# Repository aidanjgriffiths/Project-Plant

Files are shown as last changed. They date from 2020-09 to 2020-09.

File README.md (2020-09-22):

# Plantiful
#### A Powerful Embedded Monitoring Device for plant Enthusiasts
This page aims to document the source code, software and hardware incorporated in the development and production of the Plantiful prototype.

## Software
### Android Studio  
Used for developing a mobile app that will collect sensor data and provide information to the user regarding the state of their plants. 
Many people possess Android phones. Group members have experience programming in Java on this platform. 
### PHP Storm  
Modern PHP IDE for developing Web Applications within several Web Environment's. This provides our Users with a Convenient platform for viewing Plant Data, with regard to the health status of their plants, the weekly requirements from the User in terms of providing the appropriate nourishments for the Plants, and the projected requirement's in the future.
### MySQL Workbench
Interface directly to the Database hosted in the cloud, allowing for effective and simple queries and modifications to the Database
### AWS Lightsail
Web Sever Hosting Service on Amazon Web Services, which hosts the Virtual Web Server, running a Headless Ubuntu Instance, with a LAMP (LAMP) stack pre-installed on the operating system  
### AWS MySQL RDS
Relational Database Service for the Cloud MySQL Database, for access from the Web Application and Android Application. This is the central point for the back-end configuration of the MySQL Database Instance
### Arduino IDE 
IDE provides a coding platform for writing high level C/C++ based code that can be flashed to an Arduino board. 
Accessible coding platform. Runs on Windows. Basic setup and looping format. Many well-established libraries available. USB flashing. Debugging is simple using the provided serial terminal.
### AutoDesk Fusion 360 
Used for developing 3D designs for the hardware enclosure (prototype and final design). 
Accessible. At least one group member has experience developing models with this software. Parts can be assembled and animated. Enable direct export of 3D printing file. Schematic drawings are available for large scale production. 
### AutoDesk Eagle
Used for developing CAD schematic and printed circuit board designs for the embedded system final design. Program works in conjunction with Fusion 360 to purpose fit to the hardware shell.
### Cura 
Enables slicing and positioning of component pieces on 3D printing platform. 
Group member is in possession of this software and has experience using it for printing prototypes. 

## Hardware
### Uno R3 
Compact micro-processing unit with I/O ports for interfacing with moisture, temperature/humidity and light sensors. Minimal processing required except to transmit sensor data serially over Bluetooth.
Accessible, cost effective, and comes with an IDE that includes simplified coding functions for reading data from sensors and communicating serially with the proposed mobile application. Used for initial development, with later revisions using the same microcontroller (ATMEL ATMega328) in a bare configuration. 
### Moisture sensor 
DFRobot moisture sensor measures soil moisture, utilising an inbuilt transistor and associated discrete parts amplify a weak current between the probes into a 0-5v signal dependent on moisture. Will be used to determines if plant requires watering or is over-hydrated. 
Cheap, accurate and interfaces well with Arduino. No external libraries are required. 
### Temperature / Humidity sensor (DHT12)
Digital temperature and humidity sensor to determine ambient environmental parameters that determine the suitability of the conditions for optimal plant development. Highly reliable and fast response. -40 - 80C temperature range with error of +/- 0.5C, 0-100% humidity range with an error of 2-5% over the range. Easy to interface with Arduino with easy to use, highly available external libraries.
### Ambient light sensor (5kOhm Light Dependent Resistor)
Measures ambient light and reflects analog voltage to Arduino controller. Will be used to determine if the plant is receiving the correct amount of sunlight. 
Simple to use and interfaces relatively easily with Arduino requiring a single pull-up resistor as the only extra part. No additional libraries required, but basic calibration required.
### HC-05 Bluetooth module 
Enables Bluetooth connection with mobile device to communicate sensor data serially. 
Easy to setup and maintain a reliable connection with a mobile phone. Security is not a priority given the non-critical nature of the sensor data collected.

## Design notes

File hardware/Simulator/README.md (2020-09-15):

# Using the simulator

## Hardware
HC-05 should be connected via a 3.3v level shifter so that RX *from the HC-05* goes to pin 10 on the Arduino and TX *from the HC-05* goes to pin 11 on the Arduino. Also note that while you can supply the HC-05 with 5v for it's supply, things tend to be a litte more stable if run from the 3.3v from the Arduino, this will be required for the level shifter at any rate.

## Software

Once a serial connection is created to the HC-05, a single character is all that is required to illicit a response, with the idea being that this communication protocol will directly mirror that of the finished design. 

### Commands

`v` - Version: Return the version of the firmware currently installed. Simulator will return `SIMx.yy`, "proper" version will return "x.yy".
`r` - Reading: Take a reading and return all the values in a single burst. In the case of the simulator, there are defaults for all of the readings, but these readings will randomly drift for each reading.

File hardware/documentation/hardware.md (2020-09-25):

# Hardware design notes
Please see the Fritzing diagrams (or included exported JPG's) for details on how the spaghetti or breadboard versions are connected, or how the Testers are created.

# Hardware design notes - Naked MCU version

- A standard oscillator is formed using the following parts:
    * 16MHz Crystal - Across pins 9 and 10
    * 2x 22pf ceramic capacitors - tie pins 9 and 10 to ground.

- A standard 5V+ rail is generated using the following parts:
    * 7805 5V Regulator
    * 33uF Electrolytic capacitor - directly across the input pins. 
        This is a MINIMUM value part - larger is ok.
    * 9V Battery Snap - Fed into the In and Ground pins of the 7805 

- A standard 3.3V rail is generated using the following parts:
    * LM3940 3.3V regulator - Takes input from 7805 output
    * 100nF ceramic capacitor - Across the outputs of the LM3940.
        This is a precise part - a capacitance higher or lower than this
        runs the risk of an unstable or incorrect 3.3v rail

- The ATMega328 chip must have the following:
    * A 10kOhm pullup resistor to pin 1 (the reset line)
    * A small momentary switch from pin 1 to ground 
        - This is to allow programming by holding the reset pin low until the
          code is about to be uploaded, then released. This allows the bootloader
          to operate correctly and flash the new code.
    * A 47uF capacitor on the supply pins to help smooth voltage

- The bluetooth module is connected via a 3.3v level converter
    - The HC-05 must have the following:
        - The Enable pin must be tied to ground to prevent it entering AT Mode at startup
        - The VCC and ground must be sourced via the 3.3v rails
        - The TX pin on the HC-05 must be connected via the level shifter to pin 17
        - The RX pin on the HC-05 must be connected via the level shifter to pin 16

- The LDR operates with a matched 5kOhm resistor in a voltage divider configuration
    - One side of the divider goes to ground, the other to 5V, and the signal in
      between the two devices is fed into pin 23
    - PLEASE NOTE: The unit needs to be calibrated for the range of the particular LDR/resistor
      combination. Please see the README.md under the LDR Tester folder.

- The feedback LED is connected to pin 19 and ground via a 1kOhm resistor.
    - Note that this is higher than normal for a bright LED - This keeps the current
      down and therefore the battery usage lower.

- The DHT22 temperature/humidity sensor requires the following:
    - Vcc connected to the 5V rail
    - A solid ground connection
    - The data pin connected to pin 13 of the microcontroller

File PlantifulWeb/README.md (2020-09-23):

# Plantiful Web Application
The Plantiful Web Application is a Web Interface to the Plantiful Monitoring System, which allows a User to View their Data, and Analyse Statistics based on their Monitoring Activities and Health Patterns

## Hardware Infrastructure
### MySQL Cloud Database
This is used to centralise all user data for access from the Web Application. User Data is propagated from the Android Application to the Cloud Database, through the Web API. This is a one way connection between the Web Application and Android Device. The data which is propagated to the Cloud Database is never deleted, and acts as a history of the Activities of the User and the Plantiful System.

### Web Server 
The Web Server is an _Amazon Lightsail Instance_, which hosts a LAMP Stack of Web Technology. The LAMP Stack consists of the following Technologies:

+ Apache HTTP Server
+ PHP Server-Side Processing Language
+ Linux Operating System
+ MySQL Default Database (Redundant due to manual MySQL Cloud Database)

The Web Server hosts the _Hypertext Documents and Resources for the Website_, which is retrieved by a Client when requested by a Browser.

The Web Server also hosts the _Web API_ for access via the Android Application, for simple propagation of data to the Data Source.

### Client
The Client in the Computational Device which supports access the Web Application, via a Web Browser. The Client makes HTTPS requests for the Web Application from the Web Server, which supplies the Web Pages and Resources.

The Client hosts several support modules, which reduces development time. The following support modules are in the latest commit of the Web Application:

+ QR Module for Generating and Displaying QR Codes based on a generated String ID
+ JQuery Module for simpler Document Object Model (DOM) traversal
+ Chart.JS for efficient and effective Graohs and Visualisations of Data

The AJAX (Asynchronous Javascript and XML) approach is used to create Asynchronous calls to the Web Server, to retrieve certain data from the Data Source. This provides a dynamic experience for the user, and allows for changes to be made to the Web Application, based on modifications of the Data Source by other devices (for example, the Android Aplication).

### Android Device
The Android Device hosts the Android Application, which provides the functions for Monitoring Plants and Creating Plant Profiles for the User's Garden. This Data is propagated to the Database via a Web Communications Module in the Android Application. This Communciations Module interfaces with the database via Web API Calls to the database. This layer of abstraction between the Android Device and the Database allows for middle-man processing, and erroneous / currupt data prevention.

## Software Infrastructure
The following Software Stack was used to process and display the data and User Interface. 

### Web Front-End and Back-End Technologies

+ HTML5 for structuring and designing the framework and content of the Web Application
+ CSS3 for formatting and styling the Web Application 
+ PHP for Server-Side processing and access to the Data Source
+ JavaScript for client-side processing and asynchronous requests for resources from the Web Server

## Security
### SSL/ TLS Let's Encrypt
The Web Application is certified via _Let's Encrypt_ for Secure Connections. This means the Android Device and Client (Web Browser) Users can connect to the Web Server via HTTPS (Hypertext Transfer Protocol Secure), which ensures that the bidirectional communications between the Web Server and Client are encrypted, therefore preventing a large degree of Man-in-the-Middle attacks.

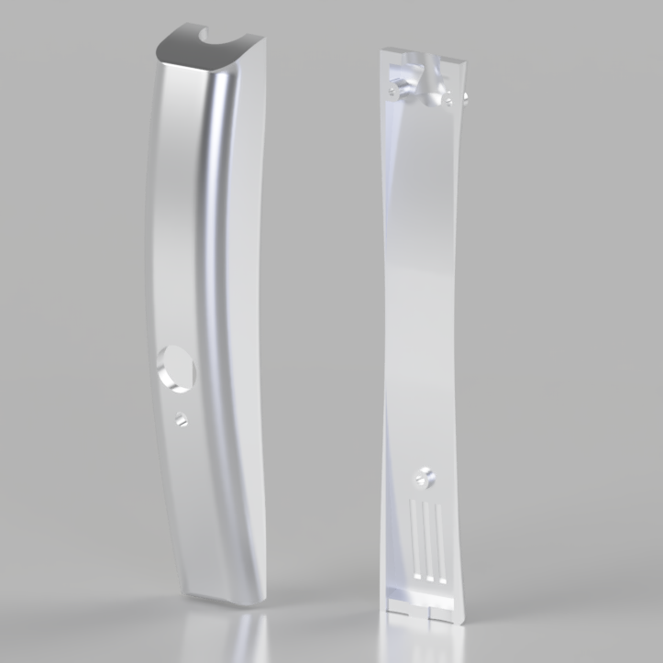
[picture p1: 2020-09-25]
hardware/3D_Models/Renders/render.PNG

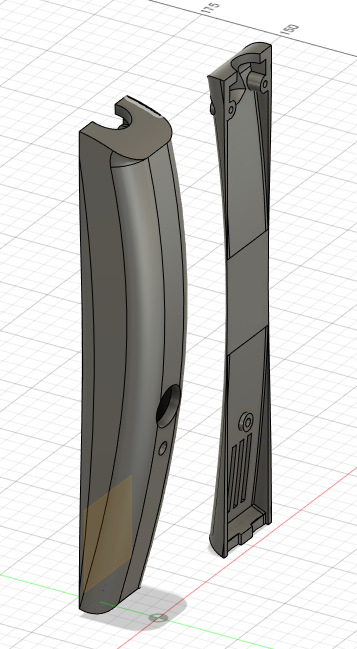
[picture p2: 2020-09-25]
hardware/3D_Models/Renders/front_v4.PNG

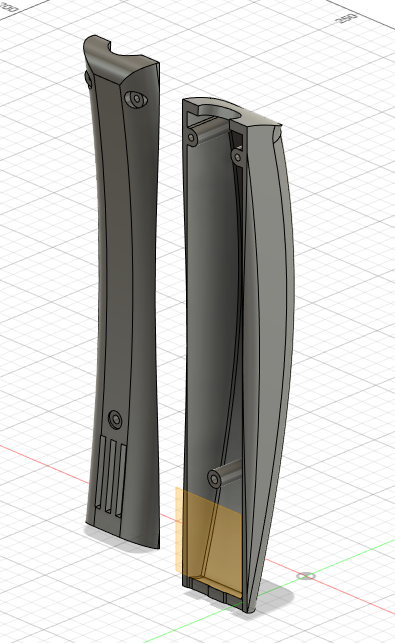
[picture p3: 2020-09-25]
hardware/3D_Models/Renders/left_v4.PNG

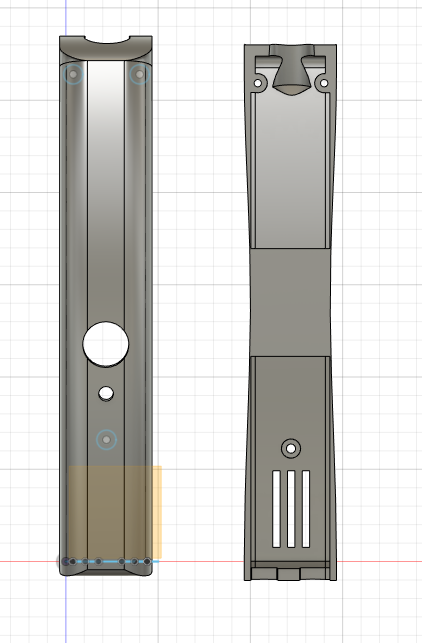
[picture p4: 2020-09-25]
hardware/3D_Models/Renders/3d_v4.PNG

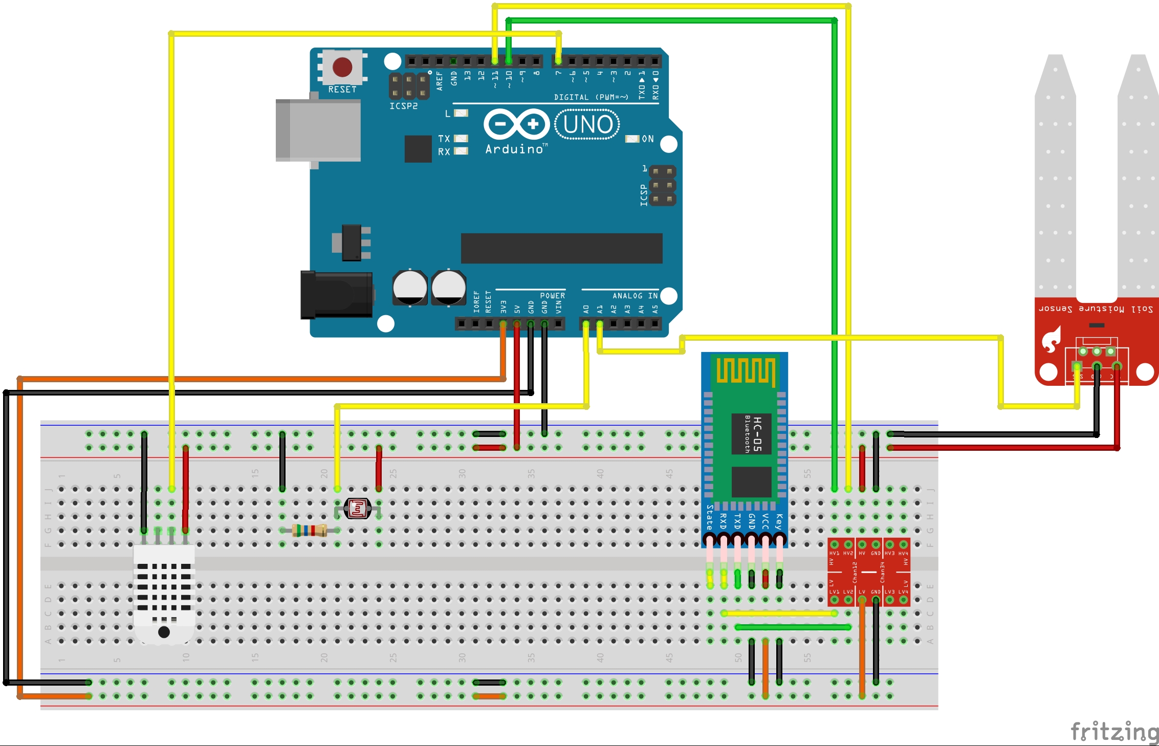
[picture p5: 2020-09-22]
hardware/documentation/Design 02 - Breadboarded.jpg

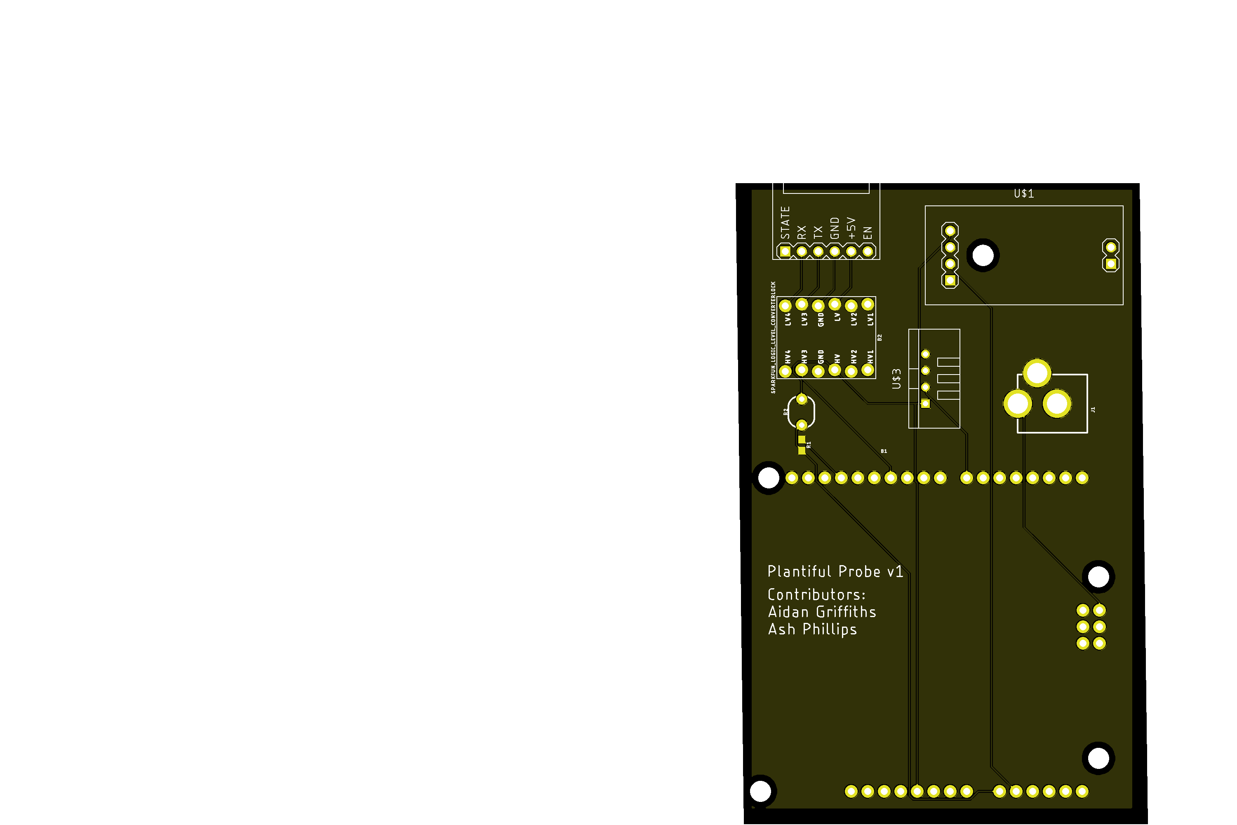
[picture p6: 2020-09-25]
hardware/PCB/Probe_PCB.png

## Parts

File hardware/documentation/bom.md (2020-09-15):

# Bill of Materials

## Introduction

This document will outline the total list of parts required for each variation/version of the hardware, including testers and intermediate revisions. This document will only detail the materials required. Connection and operation will be left to the design document.

## Suppliers

Most of the components in the below lists can be found from:
- Jaycar
- Core Electronics

## Testers
### Bluetooth Tester

* Arduino Uno/Nano
* HC-05 Bluetooth Module
* 5v-3.3v level converter module
* M-F Dupont wires

### DHT22 Tester

* Arduino Uno/Nano
* DHT22 Humidity/Temperature Sensor
* M-F Dupont wires

### LDR Tester

* Arduino Uno/Nano
* 5Kohm Light Dependent Resistor (CdS cell)
* 5.6Kohm 5% 1/4W resistor
* M-F Dupont wires
* Light duty hookup wire

### Moisture Tester

* Arduino Uno/Nano
* DFRobot resistive moisture sensor 

## "Spaghetti" version

Note: this is the first cut of the hardware design prior to using a breadboard to begin simplifying the setup.

* Arduino Uno/Nano
* HC-05 Bluetooth Module
* 5v-3.3v level converter module
* DHT22 Humidity/Temperature Sensor
* 5Kohm Light Dependent Resistor (CdS cell)
* 5.6Kohm 5% 1/4W resistor
* DFRobot resistive moisture sensor
* M-F Dupont wires
* Light duty hookup wire

## "Breadboard" version

Note: This is the first cut of the hardware design, using a breadboard to simplify the "spaghetti" wiring first used"

* Arduino Uno/Nano
* HC-05 Bluetooth Module
* 5v-3.3v level converter module
* DHT22 Humidity/Temperature Sensor
* 5Kohm Light Dependent Resistor (CdS cell)
* 5.6Kohm 5% 1/4W resistor
* DFRobot resistive moisture sensor
* M-F Dupont wires
* Light duty hookup wire
* Small breadboard (2x power rails, 2 sides of 5x30 tie points)

## "Naked MCU" version

Note: This is the first cut of the hardware design, using a raw ATMega328 microcontroller on a breadboard. This is the most physically robust design.

* Atmel ATMega328-PU DIP Microcontroller with Arduino bootloader
* USB-to-serial adapter (or Arduino Uno with ZIF Socket for programming)
* 16MHz Crystal
* 2x 22pf ceramic capacitors
* 7805 5V Regulator
* LM3940 3.3V regulator
* 9v battery snap
* 5mm green LED
* 3.3uF 5+V electrolytic capacitor
* 2x 47uF 5+V electrolytic capacitor
* 100nF ceramic capacitor
* Solid-core breadboard wiring (will be cut into individual lengths)
* 1kohm 5% 1/4w resistor
* 10kohm 5% 1/4w resistor
* Breadboard compatible momentary switch (can use a simple jumper wire if careful for reset of MCU when programming)
* HC-05 Bluetooth Module
* DHT22 Humidity/Temperature Sensor
* 5Kohm Light Dependent Resistor (CdS cell)
* 5.6Kohm 5% 1/4W resistor
* DFRobot resistive moisture sensor
* M-F Dupont wires
* Light duty hookup wire
* Small breadboard (2x power rails, 2 sides of 5x30 tie points)

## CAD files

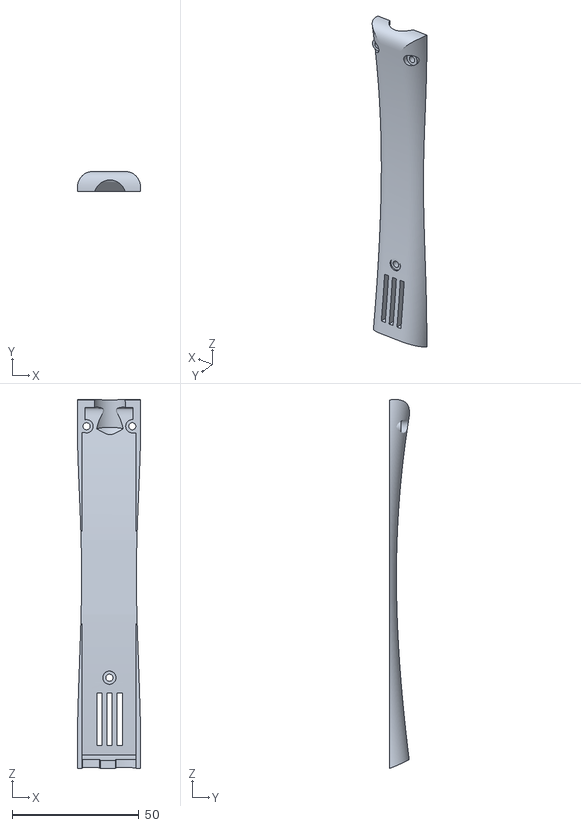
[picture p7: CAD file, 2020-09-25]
hardware/3D_Models/Models/probe_back_v5.stl
25.0 x 7.88 x 145.3

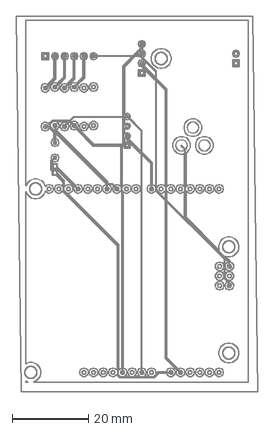
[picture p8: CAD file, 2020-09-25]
hardware/PCB/Probe_PCB.dxf
63.5 x 98.7 mm

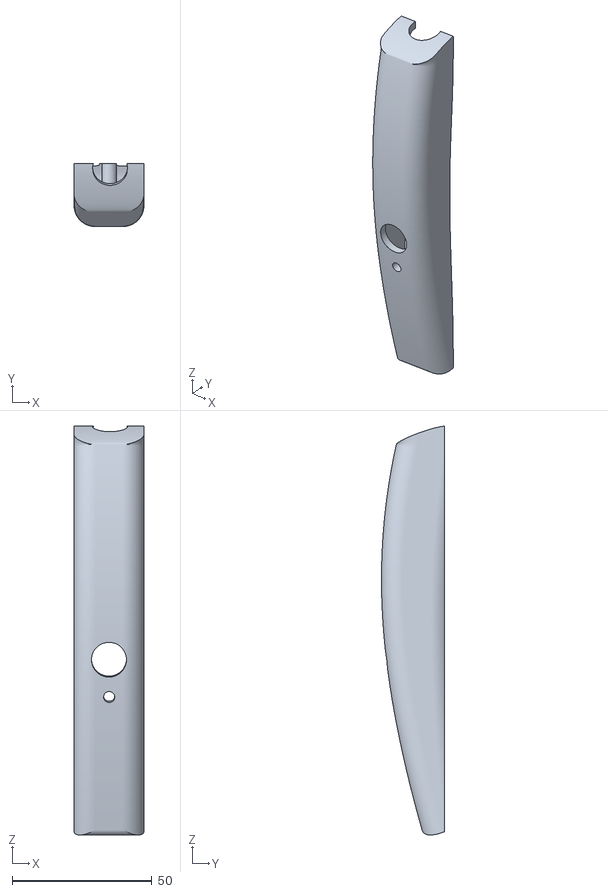
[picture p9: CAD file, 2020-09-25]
hardware/3D_Models/Models/probe_front_v5.stl
25.0 x 22.5 x 146.3

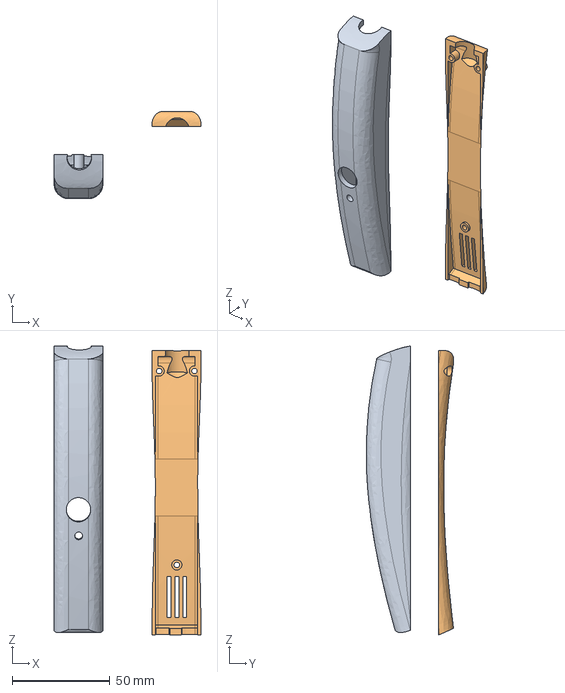
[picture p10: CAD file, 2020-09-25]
hardware/3D_Models/Models/probe_v5.step
75.0 x 44.7 x 147.5 mm

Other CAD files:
hardware/3D_Models/Models/probe_v5.obj

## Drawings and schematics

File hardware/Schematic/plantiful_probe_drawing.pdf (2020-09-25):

145.05 25 25

22.55

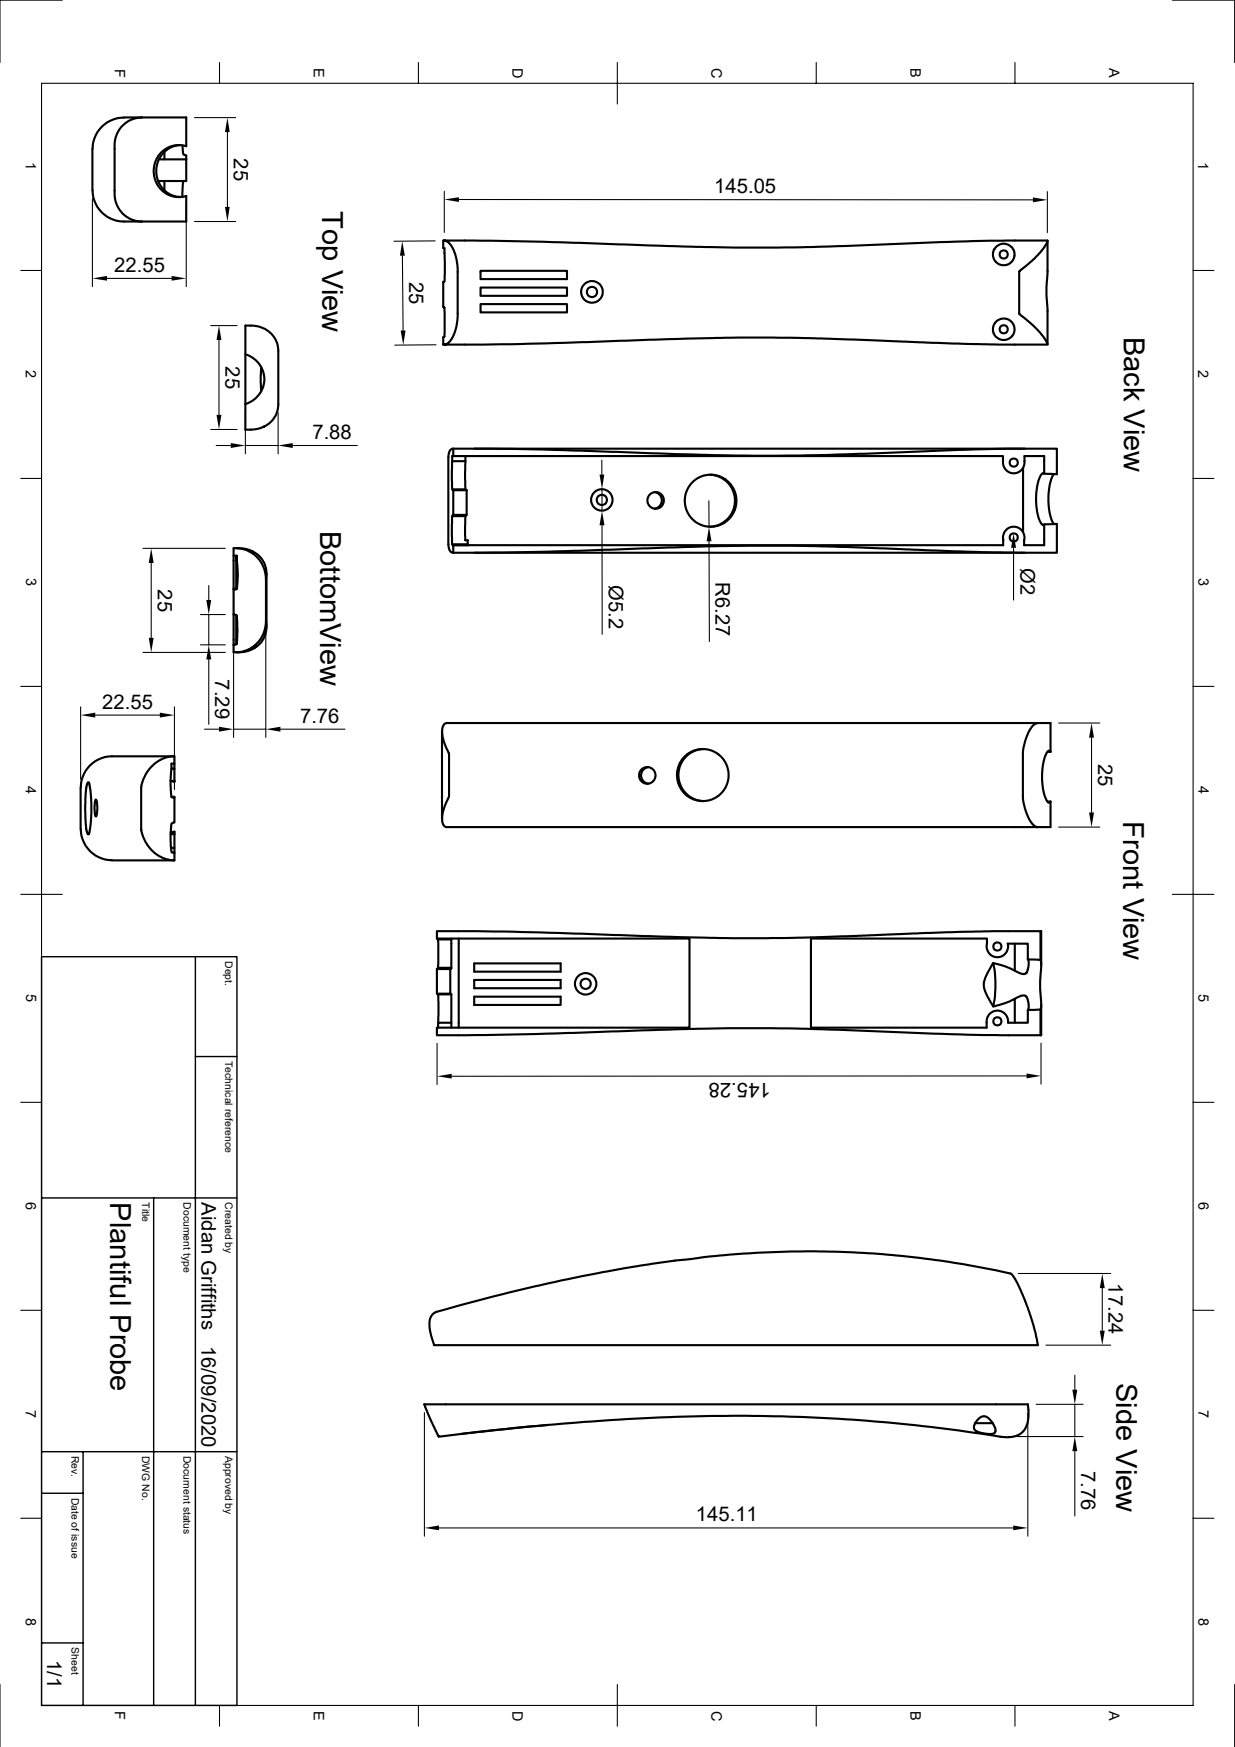
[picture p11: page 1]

1 A 2 3 4 5 6 7 8 1 2 3 4 5 6 7 8 FEDCB FEDCBA Dept. Technical reference Created by Approved by Title DWG No. Document type Document status Rev. Date of issue Sheet 16/09/2020 1/1 Plantiful Probe Aidan Griffiths Back View Front View Side View Top View

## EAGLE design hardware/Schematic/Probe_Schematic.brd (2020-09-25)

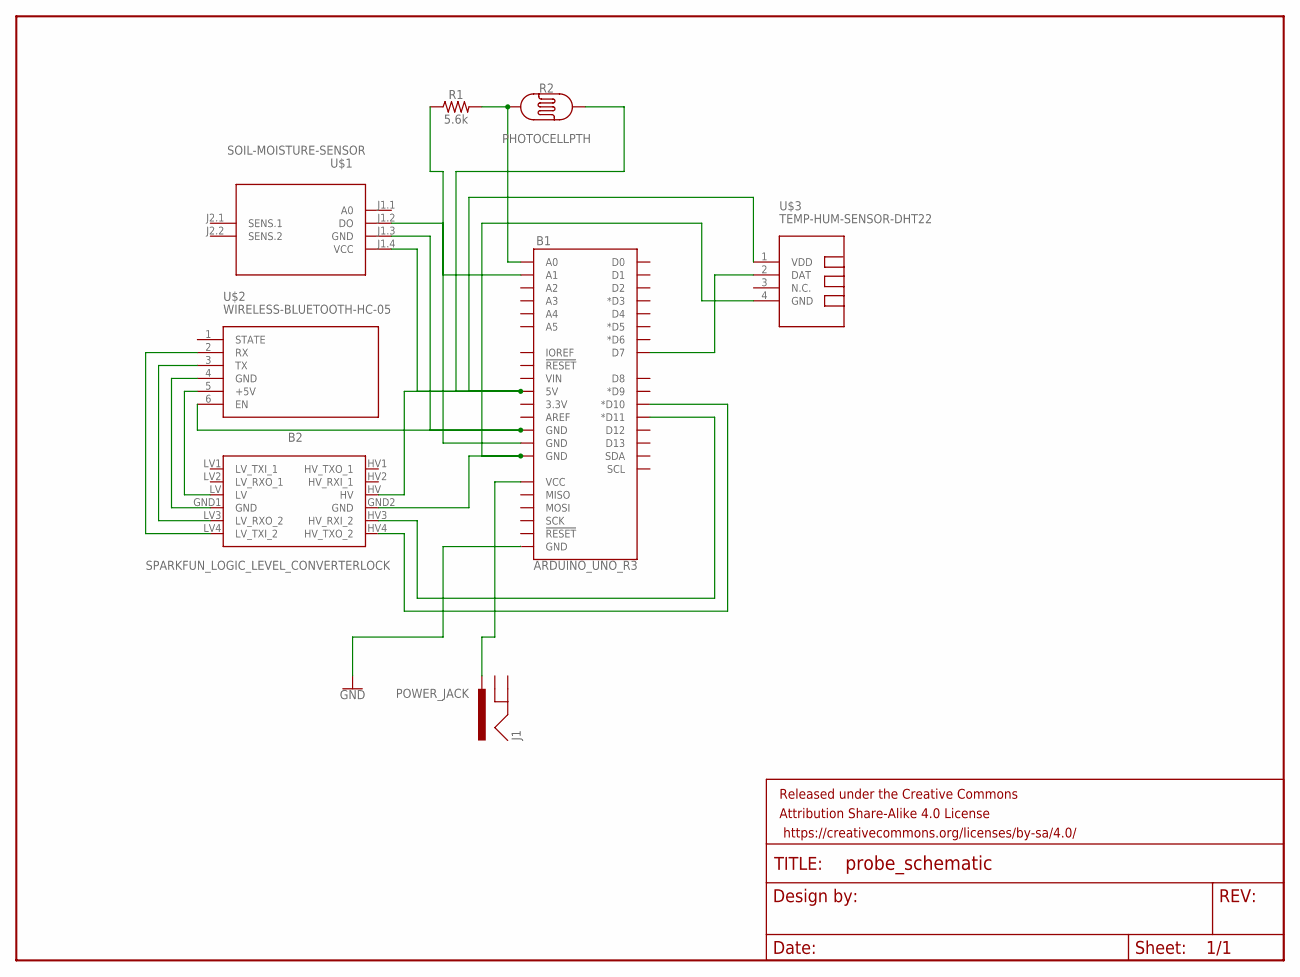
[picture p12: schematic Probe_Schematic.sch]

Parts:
B1: ARDUINO_UNO_R3; ARDUINO_R3
B2: SPARKFUN_LOGIC_LEVEL_CONVERTERLOCK; SPARKFUN_LOGIC_LEVEL_CONVERTER_LOCK
FRAME1: FRAME-LETTER; CREATIVE_COMMONS
J1: POWER_JACK; POWER_JACK_PTH
R1: 5.6k; 0603
R2: PHOTOCELLPTH; PHOTOCELL
U$1: SOIL-MOISTURE-SENSOR
U$2: WIRELESS-BLUETOOTH-HC-05
U$3: TEMP-HUM-SENSOR-DHT22

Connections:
GND: B1.GND@1 (GND)
unnamed: B1.GND@4 (GND), U$1.J1.3 (GND), U$2.6 (EN)
unnamed: B2.GND1 (GND), U$2.4 (GND)
unnamed: B2.LV, U$2.5 (+5V)
unnamed: B2.LV3 (LV_RXO_2), U$2.3 (TX)
unnamed: B2.LV4 (LV_TXI_2), U$2.2 (RX)
unnamed: B1.GND@2 (GND), B2.GND2 (GND), U$3.4 (GND)
unnamed: B1.GND@3 (GND), R1.1
unnamed: B1.D11 (*D11), B2.HV3 (HV_RXI_2)
unnamed: B1.D10 (*D10), B2.HV4 (HV_TXO_2)
unnamed: B1.D7, U$3.2 (DAT)
unnamed: B1.A1, U$1.J1.2 (DO)
unnamed: B1.VCC, J1.PWR
unnamed: B1.5V, B2.HV, R2.2, U$1.J1.4 (VCC), U$3.1 (VDD)
unnamed: B1.A0, R1.2, R2.1

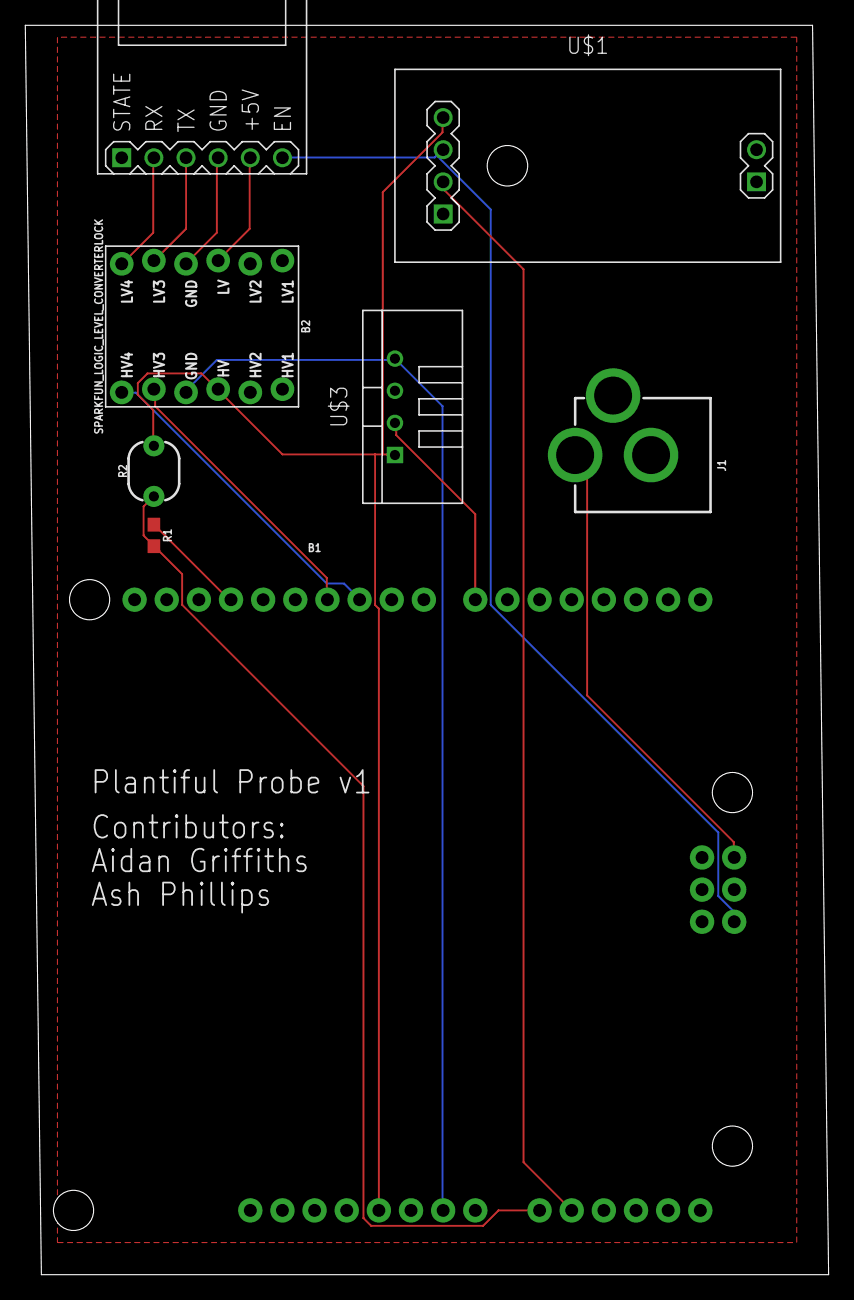
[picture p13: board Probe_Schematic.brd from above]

Board: 2 copper layers, 63.5 x 98.7 mm, 9 parts (0 on the bottom side), 14 nets.

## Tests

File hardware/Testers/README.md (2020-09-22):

# Testers

These Arduino sketches were designed with a few functions in mind. Firstly, they were used to allow the easy testing of individual components and learning how to use them and their libraries. Secondly, they allowed the hardware to be validated at various stages by having a known configuration that would be carried through various revisions, and by uploading these sketches invidivudally the various incarnations of the hardware could be compared and validated for accidental changes. Thirdly, as the device became more complicated, changes to the hardware and individual components could be easily and independently tested for proper function while avoiding the complexity of the main firmware. All of these features can be retained for future iterations as well, allowing easy and rapid improvement and validation cycles to be undertaken.

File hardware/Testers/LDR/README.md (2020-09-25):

# CdS Light Dependent Resistor

This sketch allows you to easily test the integration and function of the Cadmium-sulfide Light Dependent Resistor, or LDR. For responsive voltage swings, this unit requires a relatively accurate resistor to be used as a divider, and for calculating an approximate lux value from the device, a sensor-dependent minimum and maximum needs to be found (by physically taking the individual resistor/LDR combination to different lighting conditions). This sketch facilitates both of these things by outputting the relevant readings for adjusting the firmware. This sketch is invaluable as every CdS LDR will behave slightly different to another, so these values are required to be found for *every* sensor.

## Use

Upload the sketch to the device. Then, connect to the hardware serial UART. The device will output the current light reading, as well as maintain and display the minimum reading and maximum reading since poweron. Using the current reading you can test the responsiveness of the device (thereby validating the choice of voltage divider resistor), as well as record the minimum and maximum by moving the device from very dark environments to full bright sunlight, and using these values to set the relevant values in the main firmware sketch (RAW_LIGHT_MIN and RAW_LIGHT_MAX)

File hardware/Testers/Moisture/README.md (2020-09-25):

# DFRobot Moisture Sensor

This sensor simply returns a 0-5v signal based on the amount of moisture, with 0 being bone dry (no current between probes), and 5v, being dipped in very salty water. This sketch simply monitors and returns the current sensor reading as well as the minimum and maximum since power on. Since each sensor will behave slightly different to any other, these values are sensor-dependent and need to be found for every individual unit.

## Use

Upload the sketch to the device. Then, connect to the hardware serial UART. The device will output the current moisture reading, as well as maintain and display the minimum reading and maximum reading since poweron. Using the current reading you can test the responsiveness of the device, as well as record the minimum and maximum by moving the device from open air to a saturated salt-water solution, and using these values to set the relevant values in the main firmware sketch. (RAW_SOIL_MIN and RAW_SOIL_MAX).

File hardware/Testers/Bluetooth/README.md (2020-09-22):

# HC-05 Bluetooth module

This tester provides basic testing of the HC-05 Bluetooth module. The SoftwareSerial library is used for communication as this allows the hardware UART on the microcontroller to be left available for easy firmware updates and in-situ serial debugging. Performance is more than adequate for this use-case.

## Use
Upload the sketch, and use a serial app on a test phone unit connected via Bluetooth to the HC-05 module to send a single 'h' character. The device should respond with a "Hello!" string if the connection is successful and working.

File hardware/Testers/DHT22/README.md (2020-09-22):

# DHT22 Temperature and Humidity Sensor

This sensor reads both temperature and humidity at the same time. I have utilised the Adafruit DHT22 library as it is stable and mature, and easily installed. 

## Use

Upload this sketch, and connect via the hardware serial UART. The device will send the current readings for temperature and humidity in a human readable format, with a 2 second delay between readings.

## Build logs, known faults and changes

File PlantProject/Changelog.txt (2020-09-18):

7/8/2020 - Initial commit with animated splash screen, bluetooth connectivity and text-to-voice functionality
7/8/2020 - Added resources activity with links to 6 different flora related websites
7/8/2020 - Update to manifest to include resources activity
19/8/2020 - Profiles and monitor activities added
19/8/2020 - swipeable profile tabs added in scrollable recycler view
19/8/2020 - Notification channel established for weekly notification to check on plants
19/8/2020 - Camera, QR generator and reader included. ability to add/delete profiles.
19/8/2020 - Connecting to bluetooth shifted to monitioring acitivity
20/8/2020 - Added content to information and help activities
8/9/2020 - Font changes, updated JDK to 8.0
9/9/2020 - Added growing condition states
9/9/2020 - Added sync with web feature
10/9/2020 - Normalised slider values and added webserver connectivity
10/9/2020 - Update to monitor activity for debugging sensor values in real-time
15/9/2020 - Extra debugging textviews added to monitoring activity
16/9/2020 - Refined min and max values
18/9/2020 - Commented code

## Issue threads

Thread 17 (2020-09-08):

DOC: Create a Bill of Materials for the hardware component

AshPhillips2786, 2020-09-08:
# What
Need to create a comprehensive bill of materials outlining the various incarnations of the hardware for this project.

# Why
 This is to allow other users of this project to acquire the required sensors and other hardware materials to use the code and designs contained in this repository and replicate the setup.

# How
Take an itemised list of all required components for the following incarnations of the setup:
- All testers
- The "spaghetti" version of the hardware
- The "Breadboard" version of the hardware
- The "naked MCU" version of the hardware.

AshPhillips2786, 2020-09-21:
This issue was closed with a previous commit.

Closed 2020-09-21.

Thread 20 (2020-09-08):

First cut hardware code

AshPhillips2786, 2020-09-08:
# What
Now the hardware is working, need to upload first iteration of stable code.

aidanjgriffiths, 2020-09-16:
Closing issue due to branch being merged with master.

Closed 2020-09-16.

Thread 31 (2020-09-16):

Add Pictures of system prototype to documentation

aidanjgriffiths, 2020-09-16:
@AshPhillips2786 If you still have the built versions of the probe system from the `bom.md`, could you take some pictures of the systems and bread board so I can start to draw up some schematics and add pictures to documentation?

aidanjgriffiths, 2020-09-16:
I think I'm starting to lose hope that I can build the physical probe with the shell before the deadline so I'm going to put most of my energy of converting the "MCU" version of the embedded device into a pcd in "Fusion 360" and "Eagle". With this I think I can make a pretty refined version of the probe device.

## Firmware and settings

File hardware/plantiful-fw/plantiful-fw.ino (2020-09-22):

#include <DHT.h> //Adafruit DHT library
#include <SoftwareSerial.h>
#define VERSION "0.2"
//Comment this out when NOT debugging the hardware.
//#define DEBUG 1
#define BLUETOOTH_RX 11
#define BLUETOOTH_TX 10
#define BLUETOOTH_BAUD 9600
#define DHT_PIN 7
#define RAW_SOIL_MIN 0
#define RAW_SOIL_MAX 780
#define RAW_LIGHT_MIN 320
#define RAW_LIGHT_MAX 1017
#define ADJ_SOIL_MIN 0
#define ADJ_SOIL_MAX 100
#define ADJ_LIGHT_MIN 0
#define ADJ_LIGHT_MAX 120000

#define FEEDBACK_LED_PIN 13

DHT dht(DHT_PIN, DHT22);
SoftwareSerial bluetooth(BLUETOOTH_RX, BLUETOOTH_TX);

float humidity;
float temperature;
unsigned long light;
int moisture;
int rawLight;
int rawMoisture;

char buf[30];


void setup() {
  #ifdef DEBUG
    Serial.begin(9600);
    Serial.println("Debug Enabled");
  #endif

  pinMode(FEEDBACK_LED_PIN, OUTPUT);
  digitalWrite(FEEDBACK_LED_PIN, LOW);
  
  bluetooth.begin(BLUETOOTH_BAUD);
  dht.begin();
  delay(2000); //This is required to give the DHT time to start/stabilise
}

void loop() {
    humidity    = dht.readHumidity();
    temperature = dht.readTemperature();
    rawLight = analogRead(A0);
    rawMoisture = analogRead(A1);
    rawLight = max(RAW_LIGHT_MIN, rawLight);
    rawLight = min(RAW_LIGHT_MAX, rawLight);
    light = map(rawLight, RAW_LIGHT_MIN, RAW_LIGHT_MAX, ADJ_LIGHT_MIN, ADJ_LIGHT_MAX);
    moisture = map(rawMoisture, RAW_SOIL_MIN, RAW_SOIL_MAX, ADJ_SOIL_MIN, ADJ_SOIL_MAX);

    if (bluetooth.available())
    {
      char c = bluetooth.read();
      c = tolower(c);

      switch(c)
      {
        case('v'):
          strcpy(buf, VERSION);
          strcat(buf, "\r\n");
          bluetooth.print(buf);
        case('r'):
          digitalWrite(FEEDBACK_LED_PIN, HIGH);
          delay(100);
          digitalWrite(FEEDBACK_LED_PIN, LOW);
          char numbers[5];
          
          strcpy(buf, "T");
          strcat(buf, itoa(temperature, numbers, 10));
          strcat(buf, "H");
          strcat(buf, itoa(humidity, numbers, 10));
          strcat(buf, "L");
          strcat(buf, ltoa(light, numbers, 10));
          strcat(buf, "M");
          strcat(buf, itoa(moisture, numbers, 10));
          
          #ifdef DEBUG
            Serial.println(buf);
          #endif
          
          bluetooth.println(buf);
      }
    }
}

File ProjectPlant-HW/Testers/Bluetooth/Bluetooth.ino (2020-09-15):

#include <SoftwareSerial.h>
#define BLUETOOTH_RX 11
#define BLUETOOTH_TX 10
#define BLUETOOTH_BAUD 9600

char buf[30];

SoftwareSerial bluetooth(BLUETOOTH_RX, BLUETOOTH_TX);

void setup()
{
  bluetooth.begin(BLUETOOTH_BAUD);
}

void loop()
{
  if (bluetooth.available())
  {
    char c = bluetooth.read();
    c = tolower(c);
    if(c == 'h')
    {
      strcpy(buf, "Hello!");
      strcat(buf, "\r\n");
      bluetooth.print(buf);
    }
  }
}

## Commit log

2020-08-19 Added backend data base and monitoring
    Profiles and monitor activities added.
    Notification channel established for weekly notification to check on plants
    Camera, QR generator and reader included. Ability to add, delete profiles.
    Connecting to bluetooth shifted to montioring acitivity
2020-09-05 Removed Old DB Connector (DAL)
2020-09-08 FEAT: First cut of main hardware sketch
2020-09-08 DOC: Bill of Materials
2020-09-16 fix: exclusive random function
    I just realised that the random functions maximum parameter is exclusive so I'm just fixing my previous commit.
    [Simulator.ino]
2020-09-16 Added Graphing Support and Framework for Web App Functions
2020-09-19 Revert readability changes
    FIX: Revert previous readability changes
    [Simulator.ino]
2020-09-19 DOC: Update README hardware details
    Update the main README with more accurate details of the hardware used in the prototype.
2020-09-19 DOC: Add testers documentation
    Basic documentation on the case and use of the Testers documentation for repeat hardware testing and validation.
2020-09-20 Websync profiles and sensor data
2020-09-21 FEAT: Early design documentation
    Fritzing diagrams and JPG's of the first iterations of the hardware and the Tester layouts.
    [Design 01 - Spaghetti.fzz, Design 02 - Breadboarded.fzz, Testers.fzz]
2020-09-22 Allow visual read indication (#37)
    * CHORE: Clean up folder structure
    Clean up and rename hardware folders prior to project completion.
    * FEAT: Add visual feedback on read
    Add visual feedback on sensor read request
    * CHORE: Clean out testing code
    Remove accidentally committed testing code.
    * CHORE: Improve code structure
    Swap from if to switch to allow easier future improvements.
    [Bluetooth.ino, DHT22.ino, LDR.ino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]
2020-09-22 Revert "Allow visual read indication (#37)"
    This reverts commit 4410729191dba5b457dad01aced417a1986ac017.
    [Bluetooth.ino, DHT22.ino, LDR.ino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]
2020-09-22 Revert "Revert "Allow visual read indication""
    [Bluetooth.ino, DHT22.ino, LDR.ino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]
2020-09-25 feat: initial models and drawings of hardware shell
    [probe_back_v5.stl, probe_front_v5.stl, probe_v5.obj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]
2020-09-25 schematic and pcbs
    [Probe_PCB.dxf, Probe_Schematic.brd, Probe_Schematic.sch]

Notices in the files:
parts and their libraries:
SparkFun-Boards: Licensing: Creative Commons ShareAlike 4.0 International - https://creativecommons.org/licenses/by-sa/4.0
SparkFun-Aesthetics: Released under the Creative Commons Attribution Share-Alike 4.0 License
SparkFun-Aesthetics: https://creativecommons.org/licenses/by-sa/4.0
